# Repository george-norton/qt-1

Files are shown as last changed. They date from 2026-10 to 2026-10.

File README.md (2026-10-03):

# QT-1

QT-1 is a ZMK based Lego remote, it also works as a keyboard - so it could be used as a remote for a TV too.

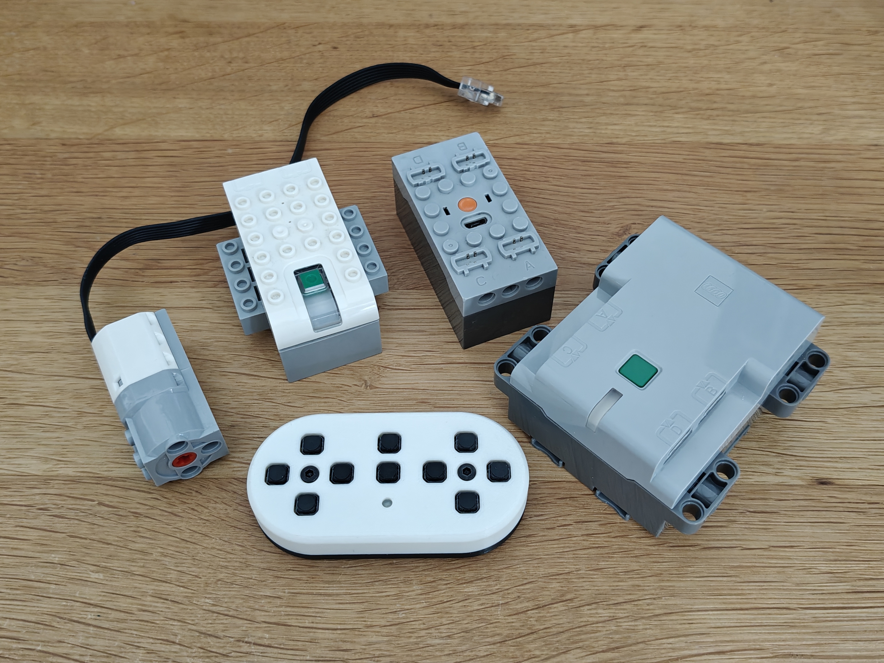
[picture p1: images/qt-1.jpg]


## Features

- ZMK studio support for remapping buttons
- Connect to up to 8 hubs at the same time
- Control up to 64 motors
- Motor speed control on a layer

## Links

- [Firmware source code](https://github.com/george-norton/zmk-keyboard-qt-1)
- [Bluetooth hub control ZMK module](https://github.com/george-norton/zmk-behavior-ble-lego-control)
- [ZMK Studio for remapping buttons](https://zmk.studio/)

## Hub compatability

QT-1 has been tested with the following hubs:
- WeDo 2.0 hub
- Lego PoweredUp! 4 port technic hub
- A 3rd party Power Functions hub (advertises as "JG_JMC-3D34")

I expect most other modern Lego hubs to work too.

## How to build

This is a DIY project, the idea is that you purchase PCBs from a manufacturer (JLCPCB, PCBWay etc..), 3D print the case and assemble it yourself. Details build instructions will follow at a later date.

You will need the following:
- Soldering iron
- Unleaded solder (this is a toy)
- Screwdriver to match the screws you choose
- Optional hot glue gun to make an LED diffuser

Bill of materials:

| Quantity | Part | Description |
| --- | --- | --- |
| 10 | [Alps SKPMAME010 switches](https://www.lcsc.com/product-detail/C115348.html) | The main controller buttons. This variant has a low actuation force. Cheaper clones are available but may require more force to press.  |
| 1 (optional) | [B3U-1000P](https://www.lcsc.com/product-detail/C231329.html) | Optional reset button. |
| 1 (optional) | 0805 LED | Optional status LED. |
| 1 (optional) | 0603 Resistor (68-100ohm) | Current limiting resistor for the status LED. The LED must not pull more than 15mA from the GPIO pin. |
| 1 | Nice!Nano v2 or clone | nrf52 based ProMicro form factor microcontroller board. |
| 2 | [4mm tall 1x12 pin header](https://www.aliexpress.com/item/4001122376295.html) | Needs to be 4mm to leave space for the battery, and for the USB socket to align. |
| 1 | 301230 battery with JST-PH plug | Lipo battery. |
| 1 | [S2B-PH-K](https://www.lcsc.com/product-detail/C19723656.html?) | 2 pin JST-PH socket. |
| 1 (optional) | [MSS22D18G2 125](https://www.lcsc.com/product-detail/C2906278.html) | Power switch |
| 1 | QT-1 PCB | |
| 1 | 3D Printed case | FDM printed in PLA (mine were ordered from JLCPCB) |
| 2 | M3 5mm Heat-set insert | |
| 2 | M3 countersunk screw 10 or 12mm | These are visible from the front - consider coloured screws. |

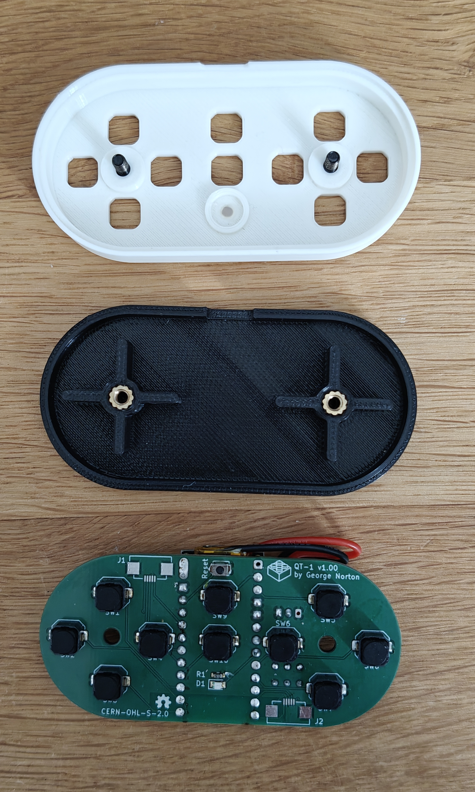
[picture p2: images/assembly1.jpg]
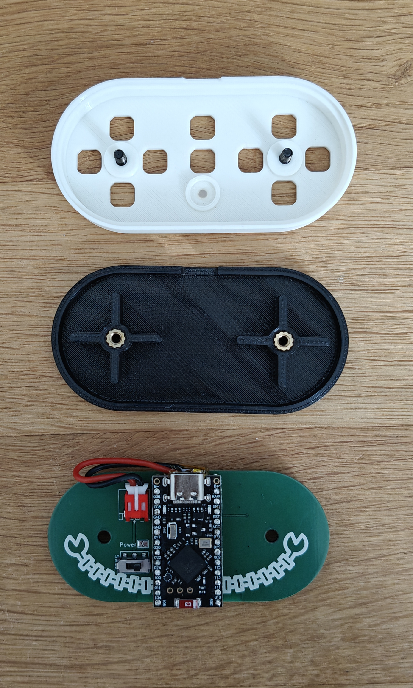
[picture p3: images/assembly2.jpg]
 

### Tips
- Take care soldering the switches - they are easy to melt if you nick them with your soldering iron.
- To solder switches, tin on pad, add some flux, place the switch then reheat the solder.
- If a switch is miss-aligned the top case will not fit. Solder the switches on one side then check everything fits before soldering on the other sides.

## Firmware

Grab prebuilt firmware from [here](https://github.com/george-norton/zmk-keyboard-qt-1/releases/), connect the remote to a computer via the USB port and double ta the reset button (or short the pads twice if no button is installed) to put it into bootloader mode. Then drag and drop the uf2 file to the drive that appears.

Once you are running QT-1 firmware, you can press the two centre buttons together to go into bootloader mode.

## Default Keymap

- The two d-pads control motors.
- The top middle button pairs hubs when pressed and turns the controller off when held.
- The bottom middle button toggles between the motor control layer and the speed control layer.
- Pressing the to middle buttons together puts the controller into bootloader mode.

## Schematic

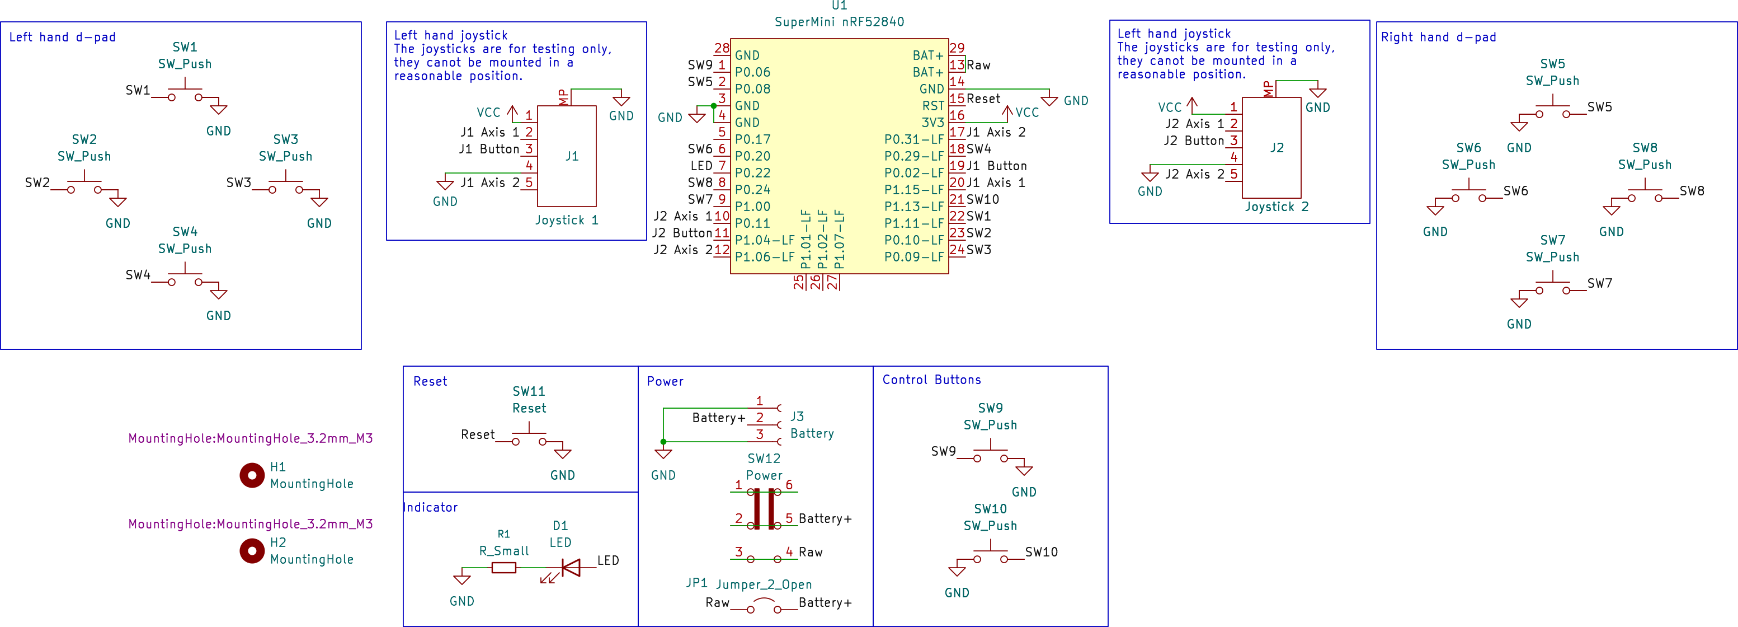
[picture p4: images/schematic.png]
Schematic


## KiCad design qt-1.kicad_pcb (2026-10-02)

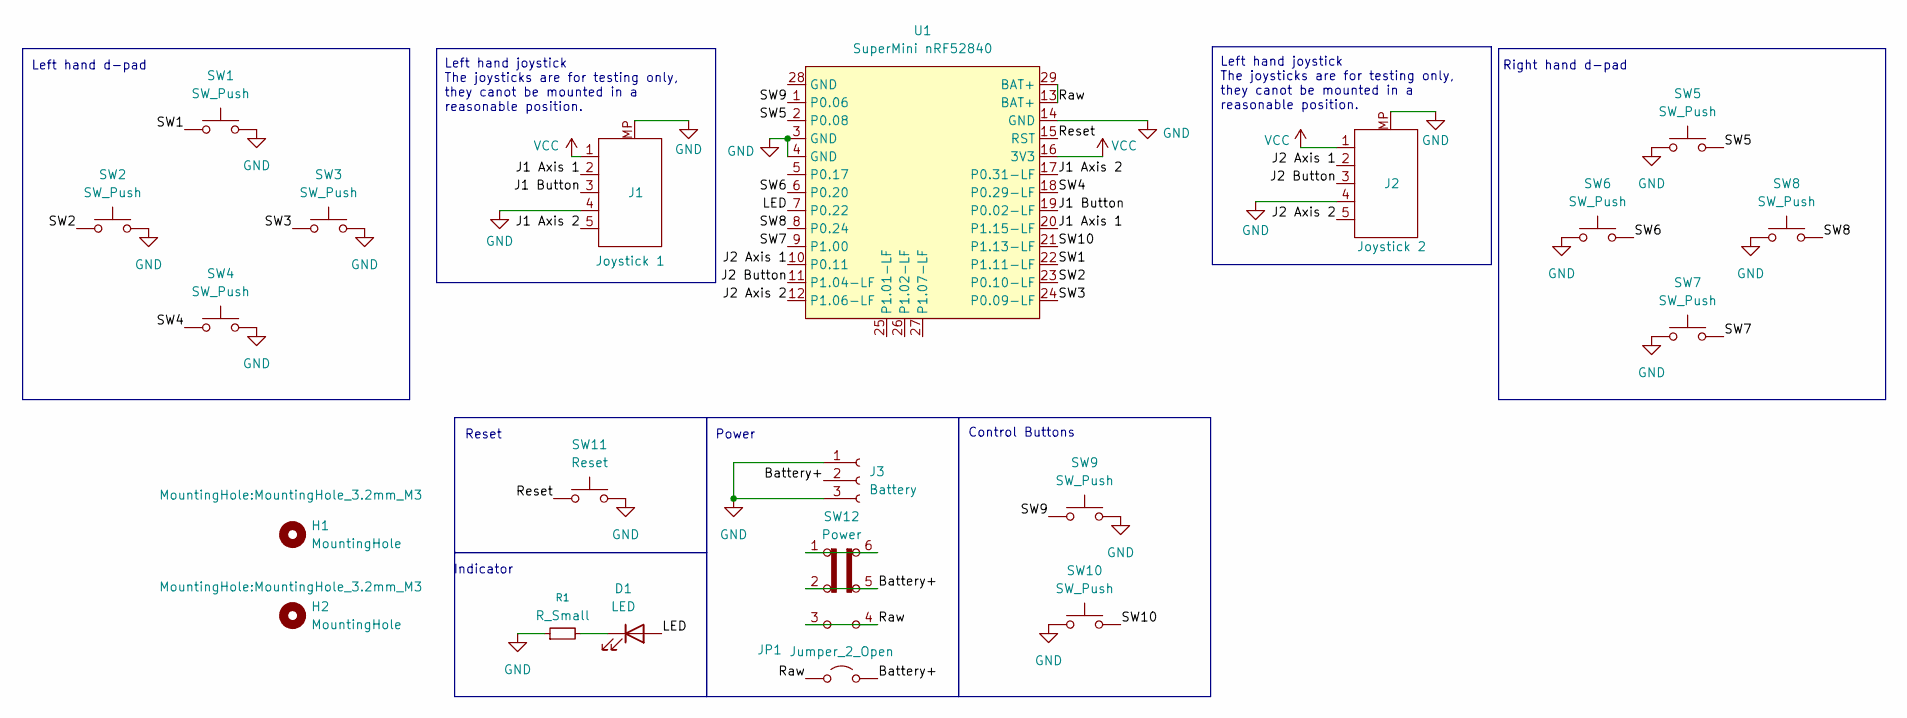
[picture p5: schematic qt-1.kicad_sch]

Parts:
D1: LED; LED_0805_2012Metric_Pad1.15x1.40mm_HandSolder
H1, H2: MountingHole; MountingHole_3.2mm_M3
J1: Joystick 1; FPC_5_TopContact
J2: Joystick 2; FPC_5_TopContact
J3: Battery; Swappable_JST_PH_S2B-PH-K_1x03_P2.00mm_Horizontal
JP1: Jumper_2_Open; SolderJumper-2_P1.3mm_Open_TrianglePad1.0x1.5mm
R1: R_Small; R_0603_1608Metric_Pad0.98x0.95mm_HandSolder
SW1, SW2, SW3, SW4, SW5, SW6, SW7, SW8, SW9, SW10: SW_Push; Alps SKPM TACT switch
SW11: Reset; SW_SPST_B3U-1000P
SW12: Power; DPDT_MSS22D18G2
U1: SuperMini nRF52840; SuperMini_nRF52840_AH_USBup

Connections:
/Battery+: J3.2, JP1.2 (B), SW12.2 (B), SW12.5 (B)
/J1 Axis 1: J1.2, U1.20 (P1.15-LF)
/J1 Axis 2: J1.5, U1.17 (P0.31-LF)
/J1 Button: J1.3, U1.19 (P0.02-LF)
/J2 Axis 1: J2.2, U1.10 (P0.11)
/J2 Axis 2: J2.5, U1.12 (P1.06-LF)
/J2 Button: J2.3, U1.11 (P1.04-LF)
/LED: D1.2 (A), U1.7 (P0.22)
/Raw: JP1.1 (A), SW12.3 (C), SW12.4 (A), U1.13 (BAT+), U1.29 (BAT+)
/Reset: SW11.1, U1.15 (RST)
/SW1: SW1.1, U1.22 (P1.11-LF)
/SW2: SW2.1, U1.23 (P0.10-LF)
/SW3: SW3.1, U1.24 (P0.09-LF)
/SW4: SW4.1, U1.18 (P0.29-LF)
/SW5: SW5.2, U1.2 (P0.08)
/SW6: SW6.2, U1.6 (P0.20)
/SW7: SW7.2, U1.9 (P1.00)
/SW8: SW8.2, U1.8 (P0.24)
/SW9: SW9.1, U1.1 (P0.06)
/SW10: SW10.2, U1.21 (P1.13-LF)
GND: J1.4, J1.MP, J2.4, J2.MP, J3.1, J3.3, R1.1, SW1.2, SW2.2, SW3.2, SW4.2, SW5.1, SW6.1, SW7.1, SW8.1, SW9.2, SW10.1, SW11.2, U1.3 (GND), U1.4 (GND), U1.14 (GND)
unnamed: D1.1 (K), R1.2
unnamed: SW12.1 (A), SW12.6 (C)
VCC: J1.1, J2.1, U1.16 (3V3)

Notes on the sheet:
Left hand joystick The joysticks are for testing only, they canot be mounted in a reasonable position.
Left hand d-pad
Right hand d-pad
Reset
Indicator
Power
Control Buttons

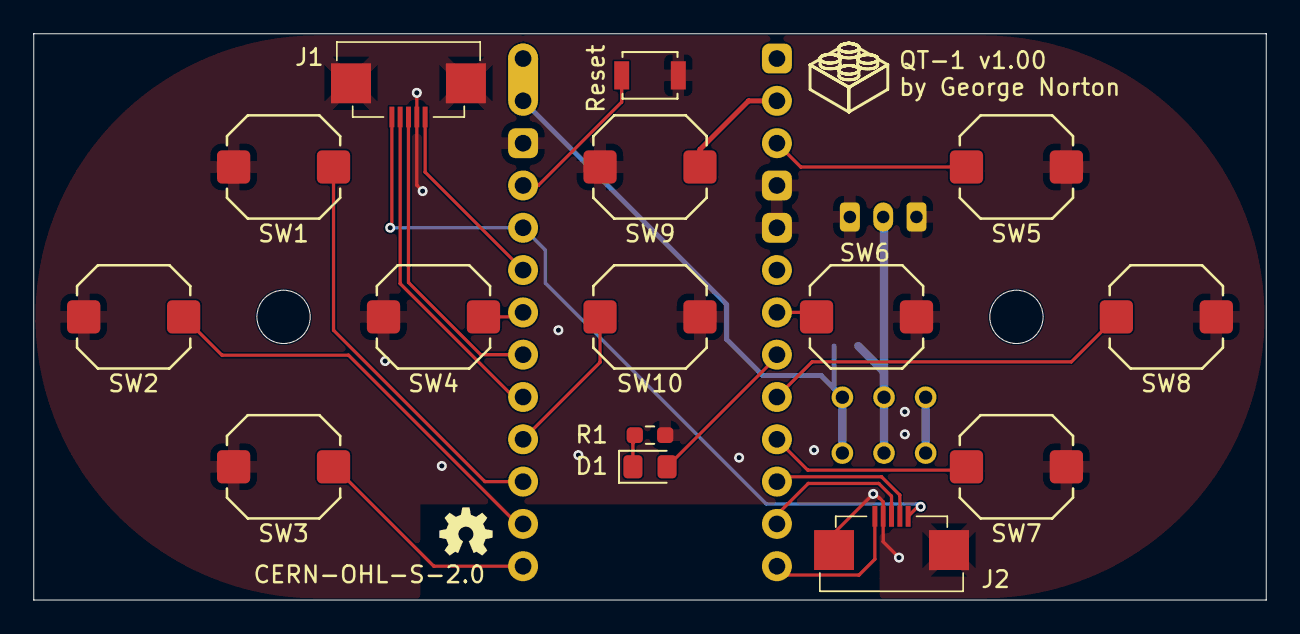
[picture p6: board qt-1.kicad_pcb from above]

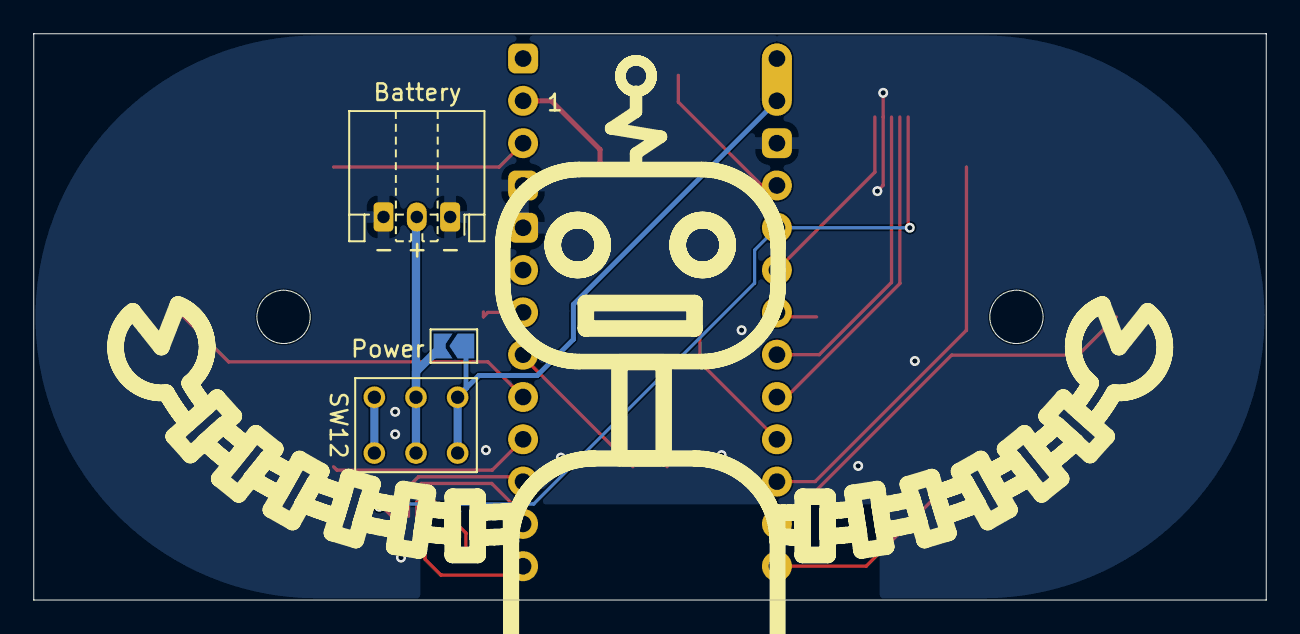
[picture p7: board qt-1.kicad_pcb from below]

Board: 2 copper layers, 74.0 x 34.0 mm, 21 parts (4 on the bottom side), 24 nets.

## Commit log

2026-08-07 Empty kicad project.
    [brick_controller.kicad_pcb, brick_controller.kicad_sch]
2026-10-02 v1 PCB
    [brick_controller.kicad_pcb, brick_controller.kicad_sch, qt-1.kicad_pcb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]

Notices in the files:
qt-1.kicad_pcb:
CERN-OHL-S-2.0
